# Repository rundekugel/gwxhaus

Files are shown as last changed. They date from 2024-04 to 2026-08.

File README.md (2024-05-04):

# gwxhaus
## Greenhouse Controller

*It's just started, not finished.*

Open hardware and firmware to control a greenhouse heating and cooling. Depends on temperature, humidity, wind and time.

An ESP32 controls the motor-controller and reads sensor data.

### Sensors
- Temperature in/out
- Humidity in/out
- Wind
- Soil moisture

There can be a lot of settings depending on sensor values and time.

### Actors
- Motors to open/close the windows
- Valves to control water
- Relais to control heating

The ESP32 is connected via another ESP32, ESP8266 or RaspberryPi to the WWW. Via mqtt the sensor data and actor positions are stored in a database and can be viewd in charts.

Optional, password protected, it's possible to change the settings and manually control the actors.

If any sensor values are out of range, or power fails, there can be messages sent via email, telegram, SMS, telephone (voip), or other channels.

Weather forecast data from Deutscher Wetterdienst https://dwd.api.bund.dev/ can be used to protect windows against storm or hail.

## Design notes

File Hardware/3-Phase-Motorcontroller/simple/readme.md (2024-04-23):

# gwx-control-motor
## Simple motor controller

Created to control a 3 phase motor to open/close windows of a greenhouse
Created with Eagle Version 7.7

Features:
- switch off motor, if window arrived at end position 
- stop for about 3 seconds, if direction changes, to prevent too high current, which could destroy power switches.

Input: 
- motor on/off
- up/down
- switches for end positions

Output:
- +/- for optocoupler of power motor switcher. Can control DC and AC, 1 to 3 phase motors.
- +/- for direction switch relais

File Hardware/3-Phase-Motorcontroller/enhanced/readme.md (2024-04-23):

# gwx-control-motor-oc
## Enhanced motor controller

Created to control a 3 phase motor to open/close windows of a greenhouse. 
Created with Eagle Version 7.7

Features:
- switch off motor, if direction changes
- switch off motor, if window arrived at end position 

Input: 
- motor on/off
- up/down
- switches for end positions. Optocoupler protected. 

Output:
- +/- for optocoupler of motorswitcher. Can control DC and AC, 1 to 3 phase motors.
- +/- for direction switch relais.

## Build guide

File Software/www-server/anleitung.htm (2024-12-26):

# Steuerung via webseite

Webadresse: https://unteroed.qc9.de/gwxhaus.php

Diese Webseite kann man mit den Browsern von fast allen Smartphones und Computern aufrufen.
z.B.: Android, IPhone, Apple MAC OSX, Windows, Linux.

Auf der Seite können die wichtigsten Informationen abgelesen werden.
Um etwas zu ändern muss man sich anmelden (Login).

Der Login-Knopf ist auf der Webseite unter der letzten Tabelle.

Man kommt dann auf diese Seite: https://unteroed.qc9.de/login.php

Daten eingeben, Knopf drücken, und man landet wieder auf der Startseite. Jetzt gibt es keinen Login-Knopf mehr, dafür ein paar andere.

[Auf] zum Fenster öffnen
[Zu] zum Fenster schliessen
[Stop] um den Motor zu stoppen, wenn man das Fenster halb offen lassen will.

Wenn es wärmer oder kälter oder zu feucht ist, dass wird due Regelung das Fenster sofort wieder in die benötigte Stellung zurückstellen. Das kann man blockieren.

[Manuell] mit diesem Knopf wird die Automatik abgeschaltet. Falls man vergisst, den manuellen Modus abzuschalten, wird der manuelle Modus nach einer bestimmten Zeit wieder abgeschaltet, damit die Planzen nicht kaputt gehen.

Wie lange der manuelle Modus aktiv ist, wird oben in roter Schrift angezeigt.

Ist die Automatik deaktiviert, also der manuelle Modus aktiv, dann gilt das für jeden, der eingeloggt ist.

Jeder Befehl dauert 10 bis 20 sek. bis er ausgeführt wird. Drückt man schnell hintereinander [manuell], haus1[auf] , haus2[auf] so kann es 20 bis 40 sek, dauern bis haus1 aufgeht. und 20 bis 60sek. bis haus2 aufgeht.

Zuviele Befehle nacheinander funktionieren nicht. Dann einfach mal wieder ein bisschen warten.

# Technische Ansicht

In der technischen Ansicht gibt es ein paar Infos mehr und auch mehr Buttons. z.B. kann man in der techn. Ansicht den manuellen Modus auf eine längere Zeit einstellen. Auch im der einfachen Ansicht ist dann der manuelle Modus so lange aktiv. Den Knopf [Set time] bitte nur benutzen, wenn die Zeit mehr als ca. 3min. falsch geht.

Passau, 2024-12-24

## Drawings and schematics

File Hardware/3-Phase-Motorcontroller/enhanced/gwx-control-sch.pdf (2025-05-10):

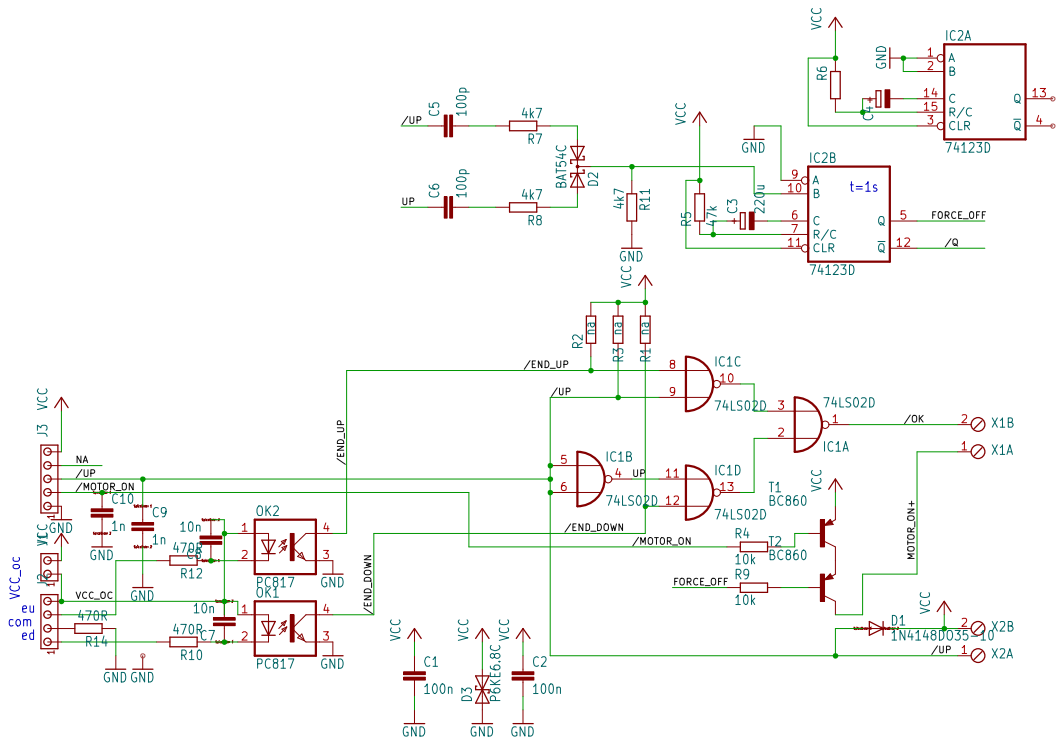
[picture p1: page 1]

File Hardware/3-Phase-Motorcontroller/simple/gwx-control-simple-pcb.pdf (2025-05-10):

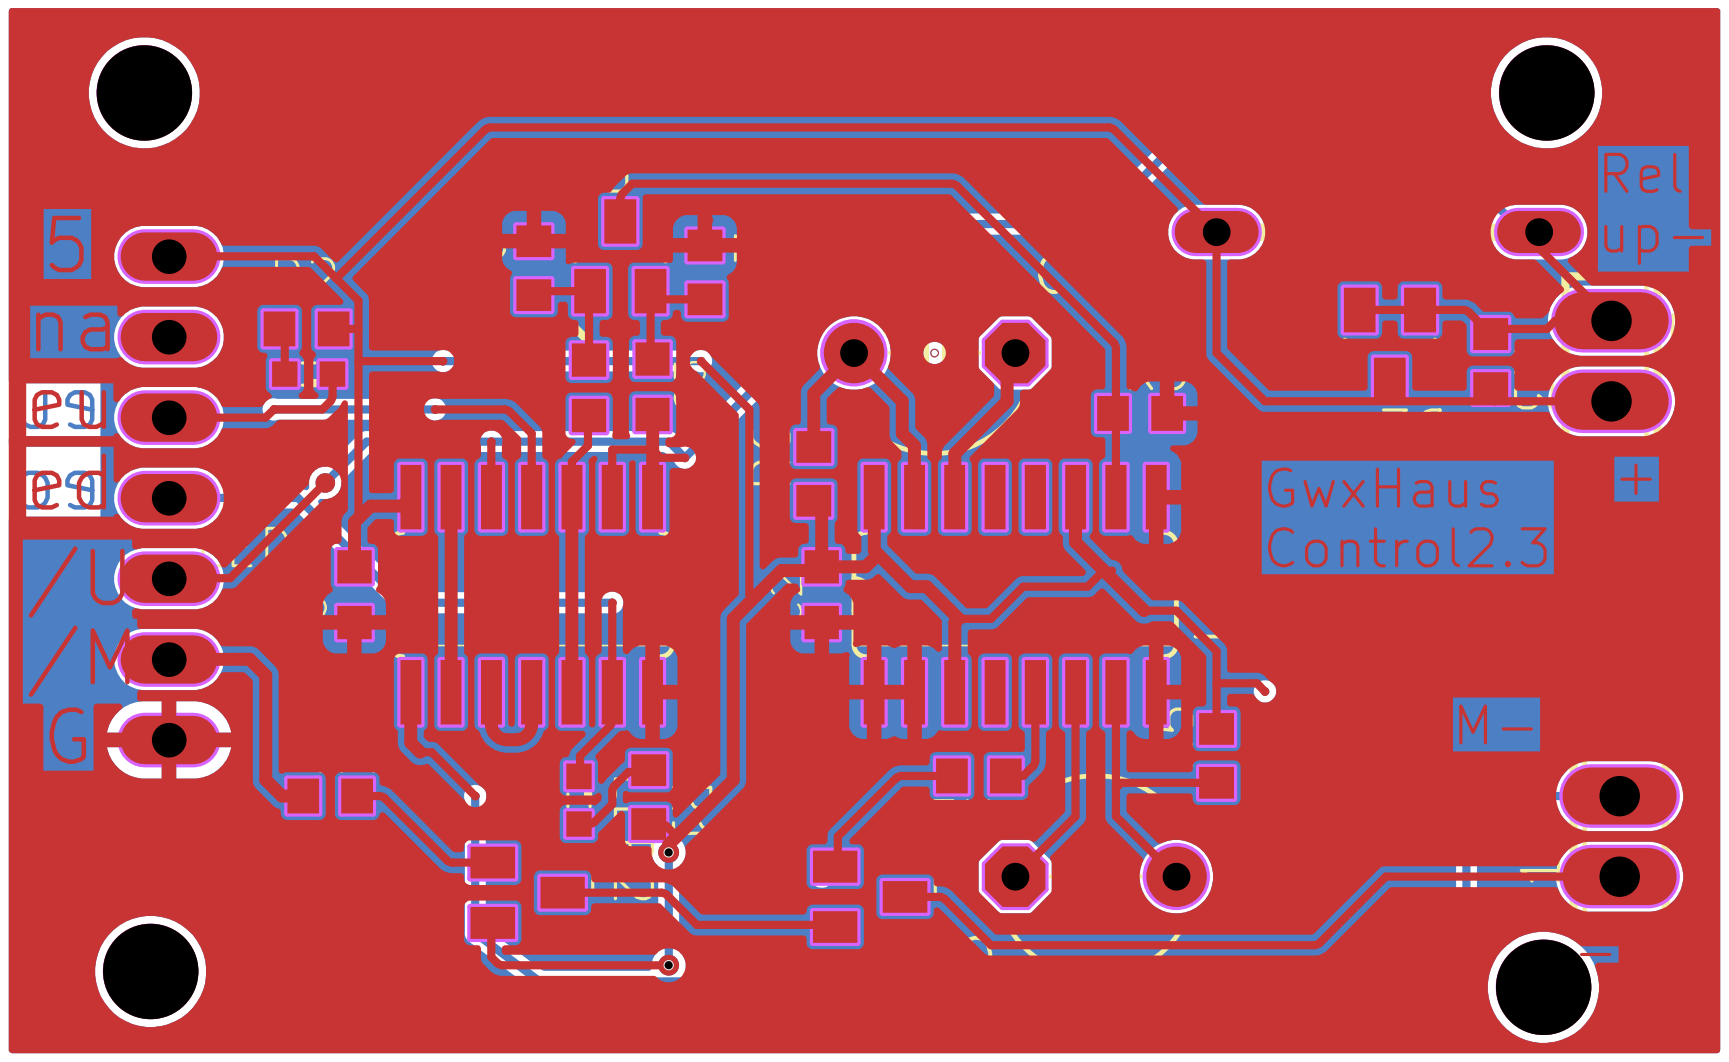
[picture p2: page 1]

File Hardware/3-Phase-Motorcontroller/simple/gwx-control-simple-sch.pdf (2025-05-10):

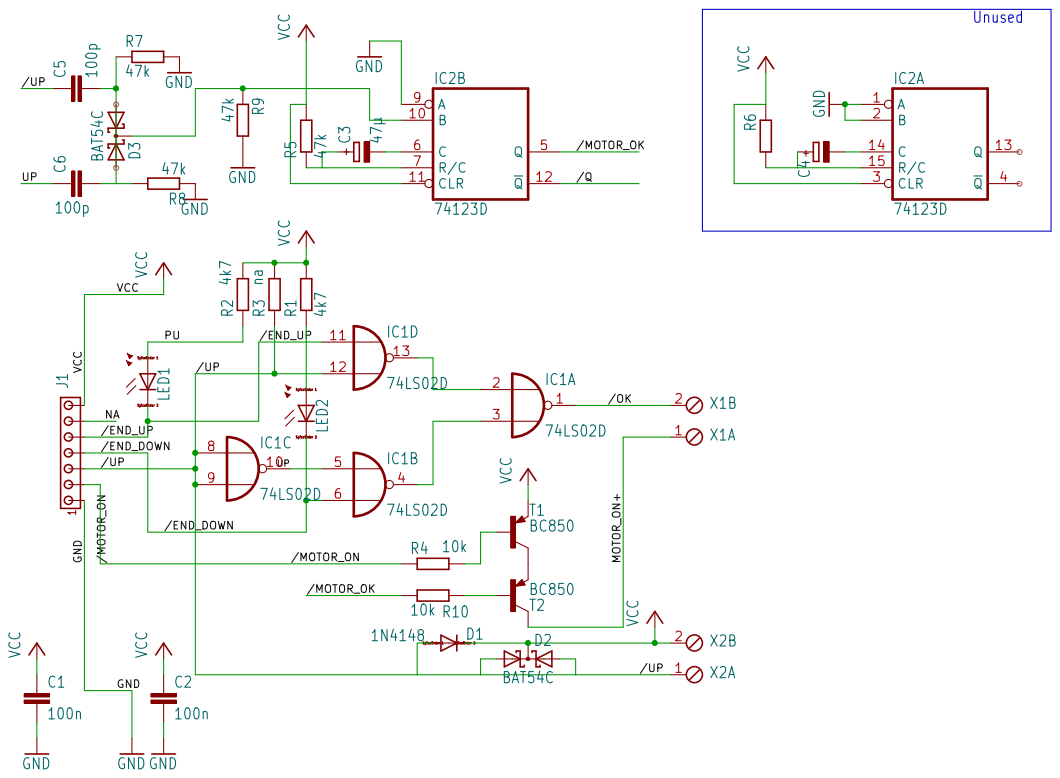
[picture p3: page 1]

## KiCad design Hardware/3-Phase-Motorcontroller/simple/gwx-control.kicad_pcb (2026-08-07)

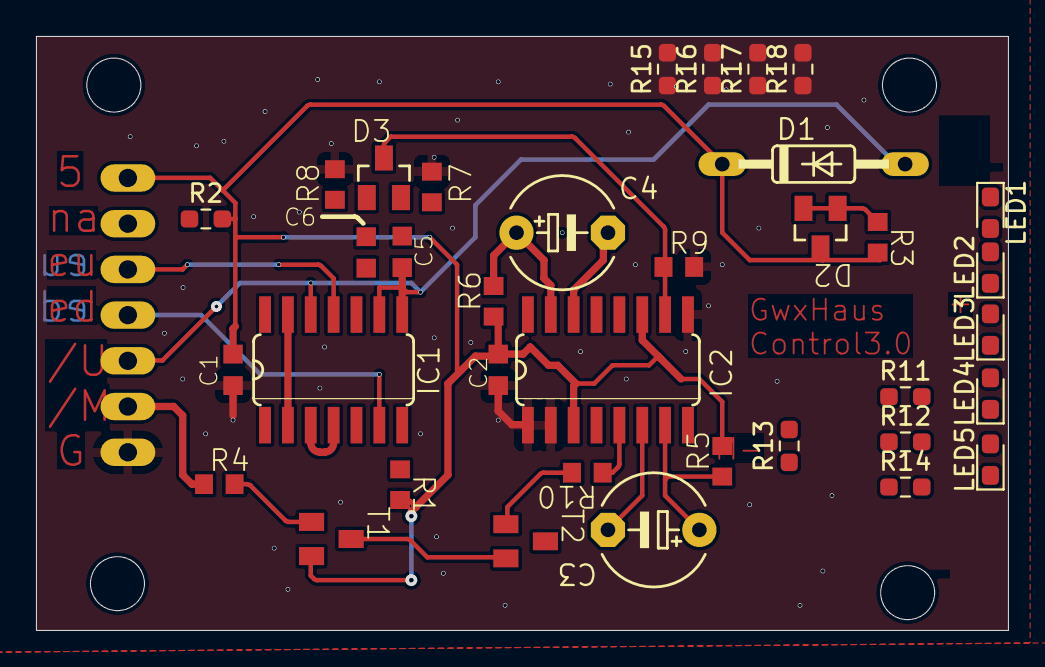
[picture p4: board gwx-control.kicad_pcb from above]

Board: 2 copper layers, 54.0 x 33.0 mm, 41 parts (1 on the bottom side), 22 nets.

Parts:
C1, C2: 100n; C0603K
C3: 47µ; E5-6
C4: CPOL-EUE5-6; E5-6
C5, C6: 1n; C0603K
D1: 1N4148; DO35-10
D2, D3: BAT54C; SOT23
IC1: 74LS02D; SO14
IC2: 74123D; SO16
J1: MTA07-100; 10X07MTA
LED1, LED2, LED3, LED4, LED5: LED_ESML0603; LED_0603_1608Metric_Pad1.05x0.95mm_HandSolder
R1, R3: 4k7; R0603
R2, R11, R12, R13, R14, R17, R18: 4k7; R_0603_1608Metric_Pad0.98x0.95mm_HandSolder
R4, R7, R8, R10: 10k; R0603
R5, R9: 47k; R0603
R6: R-EU_R0603; R0603
R15, R16: 100R; R_0603_1608Metric_Pad0.98x0.95mm_HandSolder
T1, T2: BC850; SOT23-BEC
UNK_HOLE_0: dummyfp0
UNK_HOLE_1: dummyfp1
UNK_HOLE_2: dummyfp2
UNK_HOLE_3: dummyfp3

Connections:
/UP: C6.1, R13.1
//END_DOWN: IC1.6 (I1), R16.1
//END_UP: IC1.11 (I0), R15.1, R17.1
//MOTOR_OK: IC2.5 (Q), R10.1
//MOTOR_ON: J1.2, R4.1
//UP: C5.1, D1.A, D2.1 (A1), D2.2 (A2), IC1.8 (I0), IC1.9 (I1), IC1.12 (I1), J1.3, R3.1, R18.1
GND: C1.2, C2.2, IC2.1 (A), IC2.2 (B), IC2.9 (A), J1.1, R7.2, R8.1, R9.2
unnamed: C5.2, C6.2, R7.1, R8.2
unnamed: D3.3 (CC), IC2.10 (B), R9.1
unnamed: IC1.2 (I0), IC1.13 (O)
unnamed: IC1.3 (I1), IC1.4 (O)
unnamed: IC1.5 (I0), IC1.10 (O)
unnamed: C4.-, IC2.14 (C)
unnamed: C4.+, IC2.15 (R/C), R6.2
unnamed: C3.-, IC2.6 (C)
unnamed: C3.+, IC2.7 (R/C), R5.1
unnamed: J1.4, R16.2
unnamed: J1.5, R15.2
unnamed: R4.2, T1.B
unnamed: R10.2, T2.B
unnamed: T1.C, T2.E
VCC: C1.1, C2.1, D1.C, D2.3 (CC), IC2.3 (CLR), IC2.11 (CLR), J1.7, R1.2, R2.2, R3.2, R5.2, R6.1, R11.2, R12.2, R13.2, R14.2, R17.2, R18.2, T1.E

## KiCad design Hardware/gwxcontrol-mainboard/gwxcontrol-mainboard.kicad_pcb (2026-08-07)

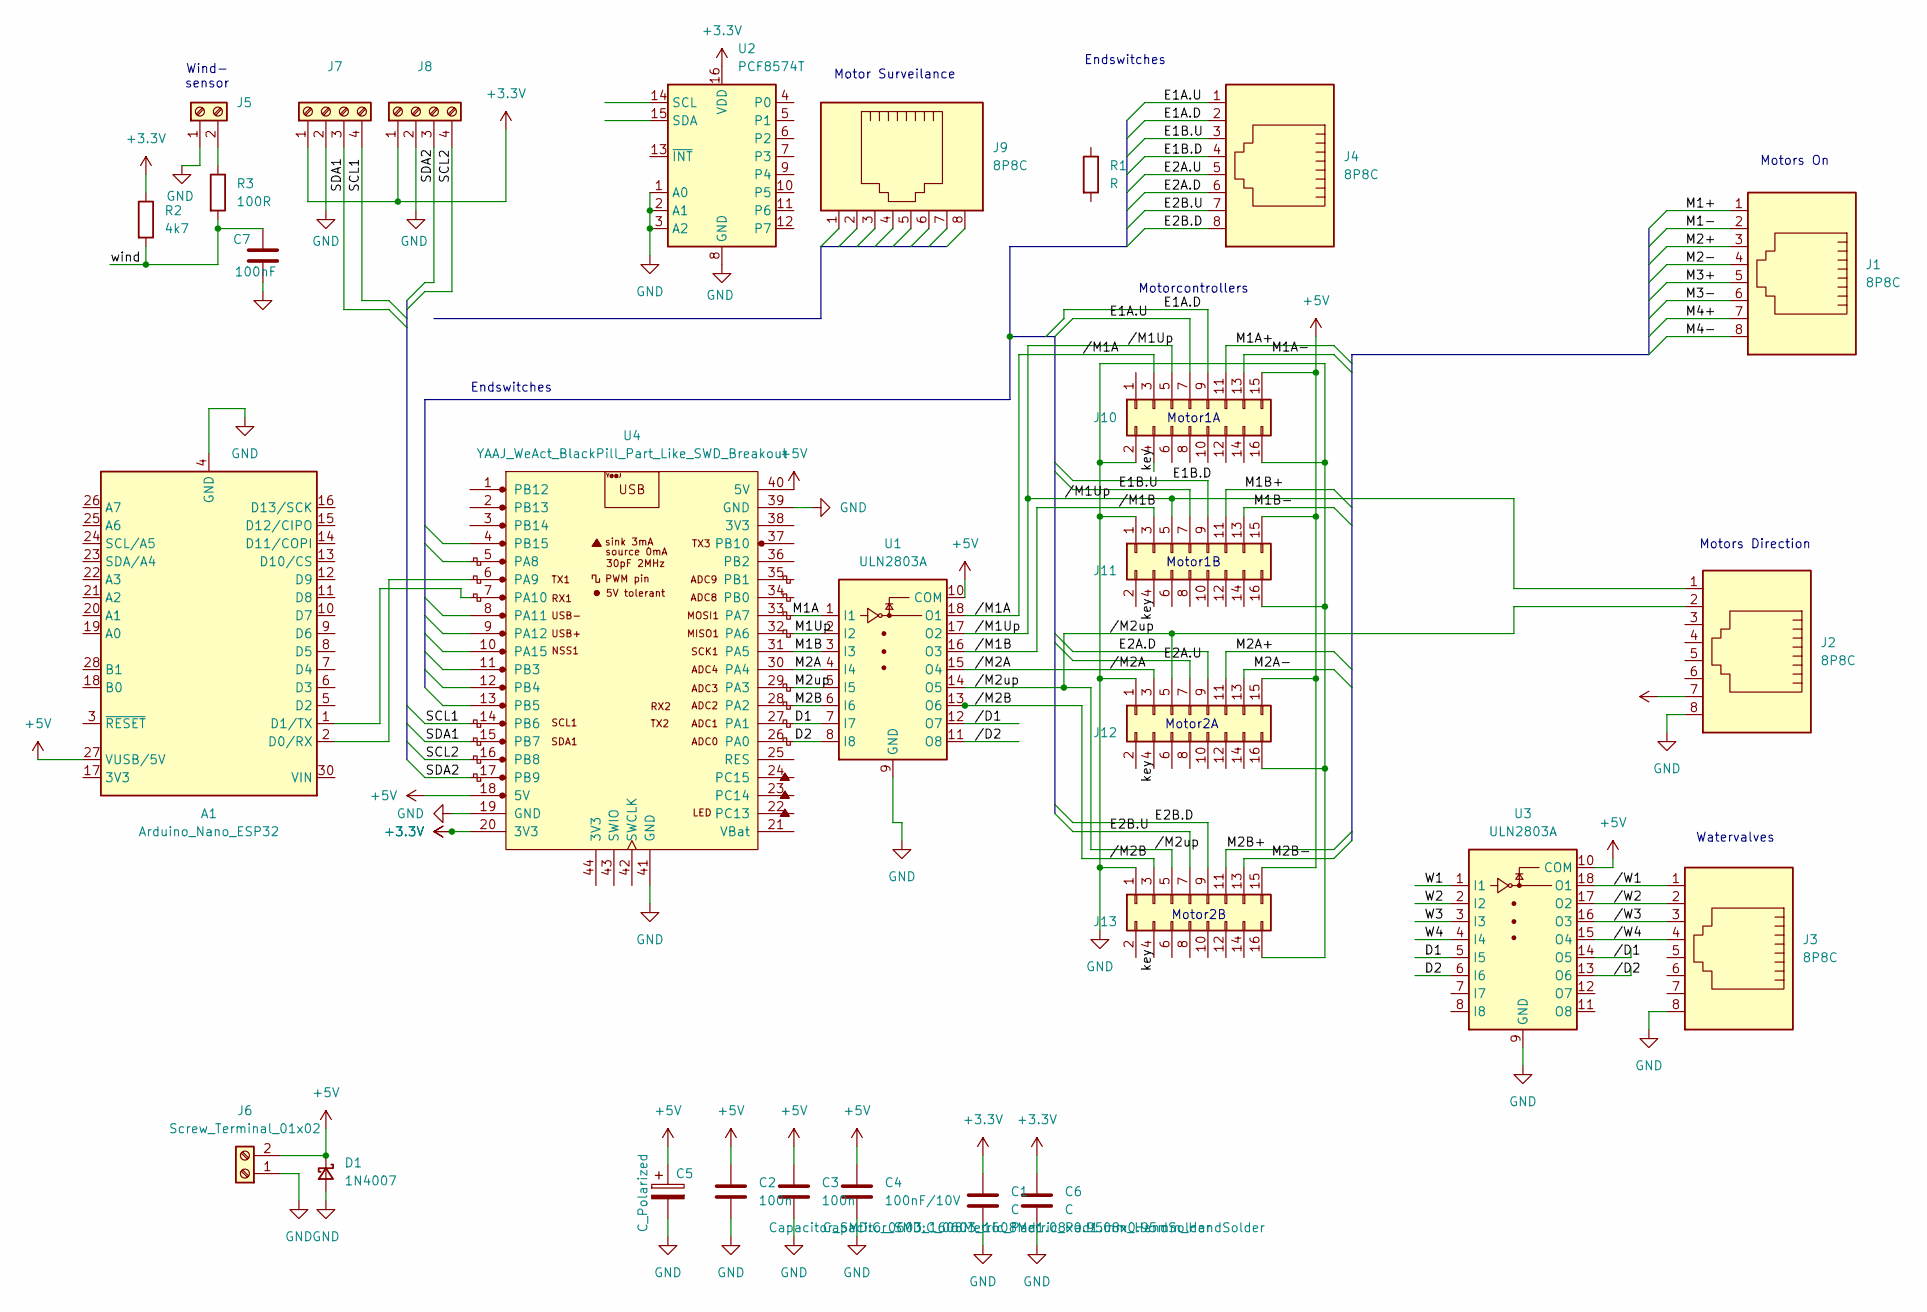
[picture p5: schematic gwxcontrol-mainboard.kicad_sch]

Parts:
A1: Arduino_Nano_ESP32; Arduino_Nano
C1, C6: C; C_0603_1608Metric_Pad1.08x0.95mm_HandSolder
C2, C3: 100n; C_0603_1608Metric_Pad1.08x0.95mm_HandSolder
C4: 100nF/10V; C_0603_1608Metric_Pad1.08x0.95mm_HandSolder
C5: C_Polarized; CP_Radial_D12.5mm_P5.00mm
C7: 100nF; C_0603_1608Metric_Pad1.08x0.95mm_HandSolder
D1: 1N4007; D_DO-41_SOD81_P10.16mm_Horizontal
J1, J2, J3, J4, J9: 8P8C; RJ45_Plug_Metz_AJP92A8813
J5, J6: Screw_Terminal_01x02; TerminalBlock_Phoenix_PTSM-0,5-2-2.5-H-THR_1x02_P2.50mm_Hor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
J7, J8: Screw_Terminal_01x04; TerminalBlock_Phoenix_PTSM-0,5-4-2.5-H-THR_1x04_P2.50mm_Hor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
J10, J11, J12, J13: Conn_02x08_Odd_Even; PinSocket_2x08_P2.54mm_Vertical
R1: R; R_0603_1608Metric_Pad0.98x0.95mm_HandSolder
R2: 4k7; R_0603_1608Metric_Pad0.98x0.95mm_HandSolder
R3: 100R; R_0603_1608Metric_Pad0.98x0.95mm_HandSolder
U1, U3: ULN2803A; DIP-18_W7.62mm_LongPads
U2: PCF8574T; SOIC-16W_7.5x10.3mm_P1.27mm
U4: YAAJ_WeAct_BlackPill_Part_Like_SWD_Breakout; YAAJ_WeAct_BlackPill_2

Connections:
+3.3V: C1.1, C6.1, J7.1, J8.1, R2.1, U2.16 (VDD), U4.20 (3V3)
+5V: A1.27 (VUSB/5V), C2.1, C3.1, C4.1, C5.1, D1.1 (K), J2.7, J6.2, J10.15, J11.15, J12.15, J13.15, U1.10 (COM), U3.10 (COM), U4.18 (5V), U4.40 (5V)
/D1: U1.7 (I7), U3.5 (I5), U4.27 (PA1)
/D2: U1.8 (I8), U3.6 (I6), U4.26 (PA0)
/E1A.D: J4.2, J10.9
/E1A.U: J4.1, J10.7
/E1B.D: J4.4, J11.9
/E1B.U: J4.3, J11.7
/E2A.D: J4.6, J12.9
/E2A.U: J4.5, J12.7
/E2B.D: J4.8, J13.9
/E2B.U: J4.7, J13.7
/M1+: J1.1
/M1-: J1.2
/M1A+: J10.11
/M1A-: J10.13
/M1B: U1.3 (I3), U4.31 (PA5)
/M1B+: J11.11
/M1B-: J11.13
/M1Up: U1.2 (I2), U4.32 (PA6)
/M2+: J1.3
/M2-: J1.4
/M2A: U1.4 (I4), U4.30 (PA4)
/M2A+: J12.11
/M2A-: J12.13
/M2B: U1.6 (I6), U4.28 (PA2)
/M2B+: J13.11
/M2B-: J13.13
/M2up: U1.5 (I5), U4.29 (PA3)
/M3+: J1.5
/M3-: J1.6
/M4+: J1.7
/M4-: J1.8
/SCL1: J7.4, U4.14 (PB6)
/SCL2: J8.4, U4.16 (PB8)
/SDA1: J7.3, U4.15 (PB7)
/SDA2: J8.3, U4.17 (PB9)
/W1: U3.1 (I1)
/W2: U3.2 (I2)
/W3: U3.3 (I3)
/W4: U3.4 (I4)
/key: J10.4
/wind: C7.2, R2.2, R3.2
//D1: U1.12 (O7), U3.14 (O5)
//D2: U1.11 (O8), U3.13 (O6)
//M1A: J10.3, U1.18 (O1)
//M1B: J11.3, U1.16 (O3)
//M1Up: J2.1, J10.5, J11.5, U1.17 (O2)
//M2A: J12.3, U1.15 (O4)
//M2B: J13.3, U1.13 (O6)
//M2up: J2.2, J12.5, J13.5, U1.14 (O5)
//W1: J3.1, U3.18 (O1)
//W2: J3.2, U3.17 (O2)
//W3: J3.3, U3.16 (O3)
//W4: J3.4, U3.15 (O4)
GND: A1.4 (GND), A1.29 (GND), C1.2, C2.2, C3.2, C4.2, C5.2, C6.2, C7.1, D1.2 (A), J2.8, J3.8, J5.1, J6.1, J7.2, J8.2, J10.2, J10.16, J11.1, J11.16, J12.1, J12.16, J13.1, J13.16, U1.9 (GND), U2.1 (A0), U2.2 (A1), U2.3 (A2), U2.8 (GND), U3.9 (GND), U4.19 (GND), U4.39 (GND), U4.41 (GND)
unnamed: A1.2 (D0/RX), U4.6 (PA9)
unnamed: A1.1 (D1/TX), U4.7 (PA10)
unnamed: J5.2, R3.1
unnamed: U1.1 (I1), U4.33 (PA7)

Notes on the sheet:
Endswitches
Watervalves
Wind- sensor
Motors Direction
Motor1A
Motor Surveilance
Motor2B
Motorcontrollers
Motor1B
Motors On
Motor2A

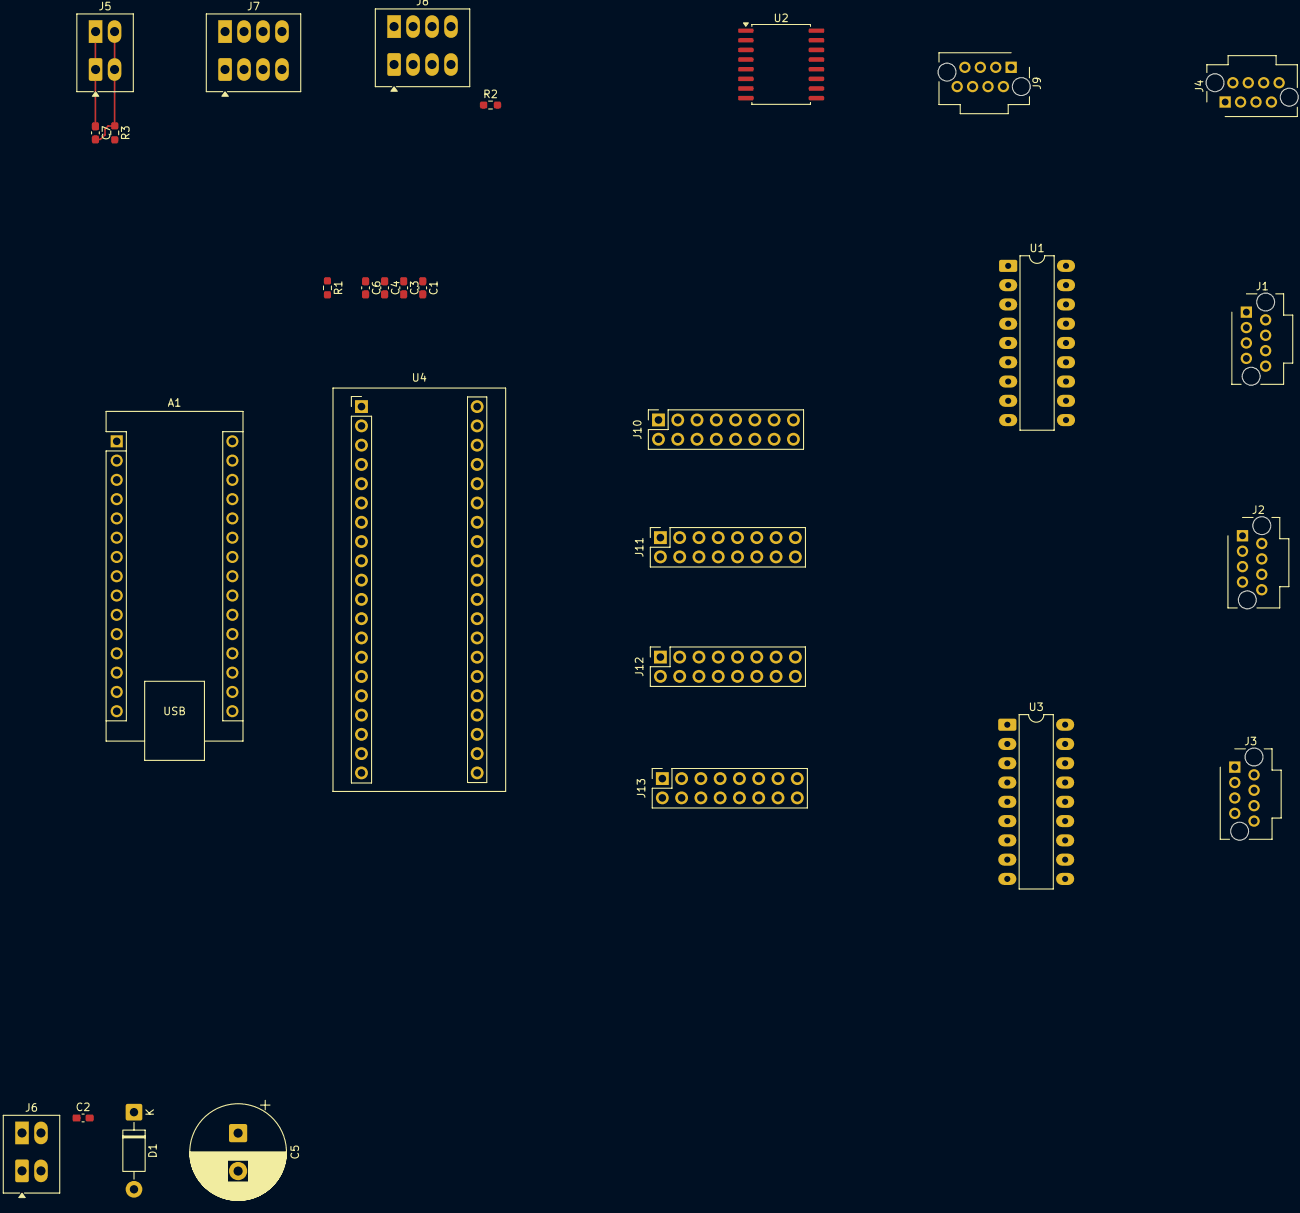
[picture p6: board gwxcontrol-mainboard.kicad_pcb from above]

Board: 2 copper layers, 29 parts (0 on the bottom side), 39 nets.

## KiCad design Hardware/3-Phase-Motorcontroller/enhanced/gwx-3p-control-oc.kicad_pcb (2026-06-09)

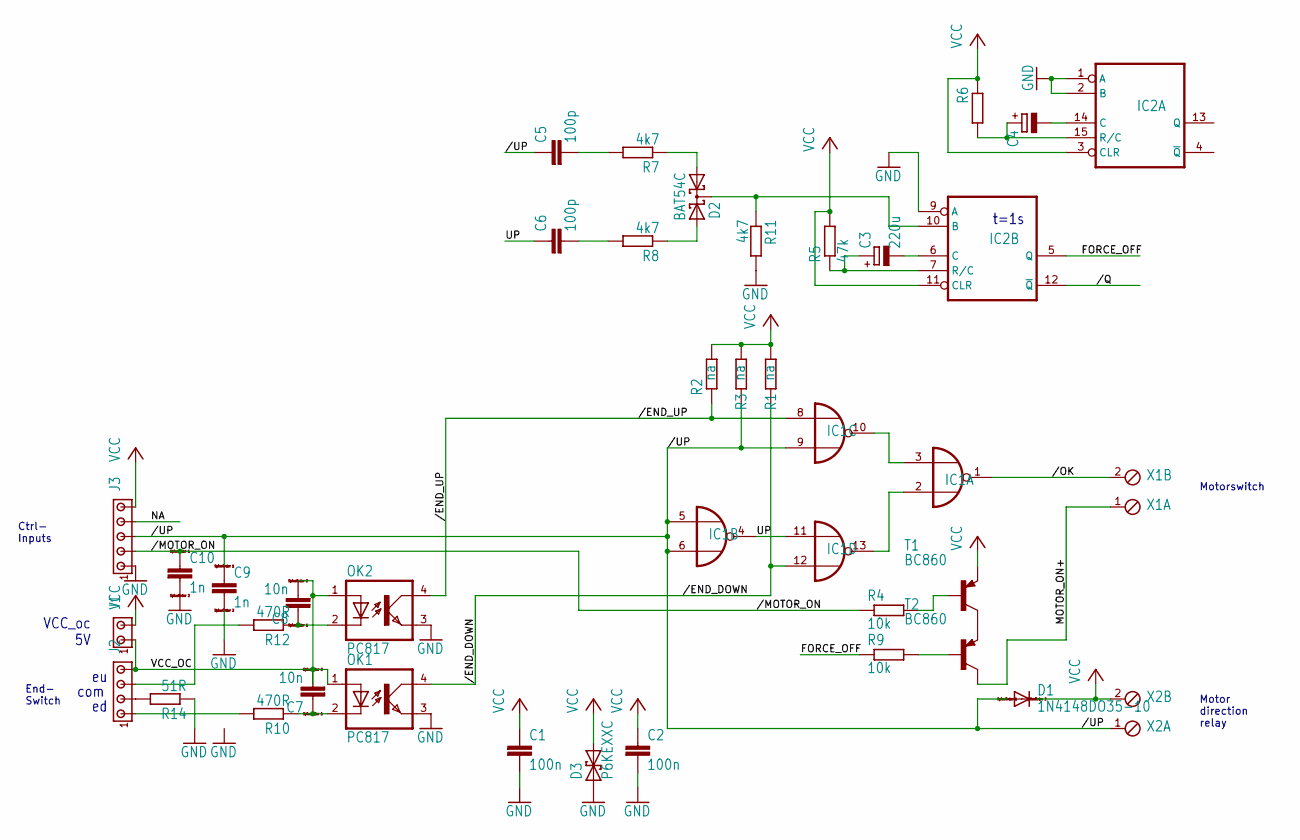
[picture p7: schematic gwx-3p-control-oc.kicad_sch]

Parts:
C1, C2: 100n; C0603K
C3: 220u; E5-6
C4: CPOL-EUE5-6; E5-6
C5, C6: 100p; C0603K
C7, C8: 10n; C0603
C9, C10: 1n; C0603
D1: 1N4148DO35-10; DO35-10
D2: BAT54C; SOT23
D3: P6KEXXC; CB417-15
IC1: 7402D; SO14
IC2: 74123D; SO16
J1: MTA02-100; 10X02MTA
J2: MTA04-100; 10X04MTA
J3: MTA05-100; 10X05MTA
OK1, OK2: PC817; DIL04
R1, R2, R3: na; R0603
R4, R9: 10k; R0603
R5: 47k; R0603
R6: R-EU_R0603; R0603
R7, R8, R11: 4k7; R0603
R10, R12: 470R; R0603
R14: 51R; R_0603_1608Metric
T1, T2: BC860; SOT23-BEC
X1, X2: MPT2; 2POL254

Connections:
/ED: J2.1, R10.2
/END_DOWN: IC1.12 (I1), OK1.4 (COL), R1.1
/END_UP: IC1.8 (I0), OK2.4 (COL), R2.1
/EU: J2.3, R12.2
/MOTOR_ON: C10.1, J3.2, R4.1
/OK: IC1.1 (O), X1.2
/Q: IC2.12 (~Q)
/UP: C5.1, C9.1, D1.A, IC1.5 (I0), IC1.6 (I1), IC1.9 (I1), J3.3, R3.1, X2.1
ECOM: J2.2, R14.2
FORCE_OFF: IC2.5 (Q), R9.1
GND: C1.2, C2.2, C9.2, C10.2, D3.A (1), IC1.7 (GND), IC2.1 (A), IC2.2 (B), IC2.8 (GND), IC2.9 (A), J3.1, OK1.3 (EMIT), OK2.3 (EMIT), R11.2, R14.1; also elsewhere on the board
MOTOR_ON+: T2.C, X1.1
unnamed: C3.+, IC2.7 (R/C), R5.1
unnamed: C3.-, IC2.6 (C)
unnamed: C4.+, IC2.15 (R/C), R6.2
unnamed: C5.2, R7.2
unnamed: IC1.3 (I1), IC1.10 (O)
unnamed: IC1.2 (I0), IC1.13 (O)
unnamed: C6.2, R8.2
unnamed: D2.3 (CC), IC2.10 (B), R11.1
unnamed: C4.-, IC2.14 (C)
unnamed: R4.2, T1.B
unnamed: R9.2, T2.B
unnamed: T1.C, T2.E
unnamed: D2.1 (A1), R7.1
unnamed: C7.1, OK1.2 (C), R10.1
unnamed: C8.1, OK2.2 (C), R12.1
unnamed: D2.2 (A2), R8.1
UP: C6.1, IC1.4 (O), IC1.11 (I0)
VCC: C1.1, C2.1, D1.C, D3.C (2), IC1.14 (VCC), IC2.3 (CLR), IC2.11 (CLR), IC2.16 (VCC), J1.2, J3.5, R1.2, R2.2, R3.2, R5.2, R6.1, T1.E, X2.2
VCC_OC: C7.2, C8.2, J1.1, J2.4, OK1.1 (A), OK2.1 (A)

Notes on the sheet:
VCC_oc 5V
Motorswitch
com
Motor direction relay
End- Switch
t=1s
Ctrl- Inputs

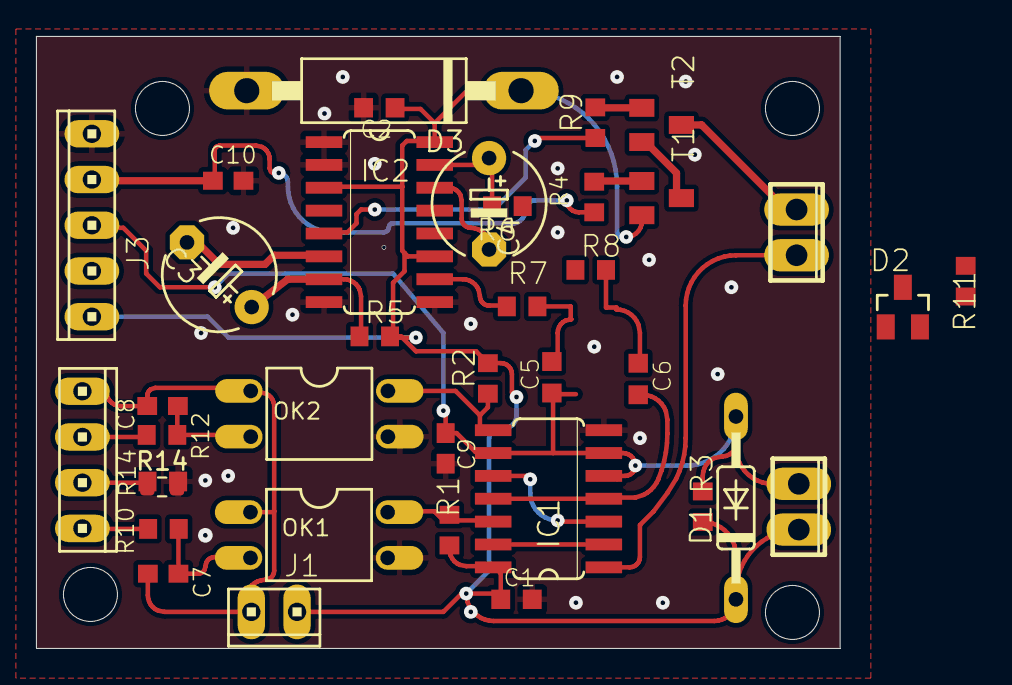
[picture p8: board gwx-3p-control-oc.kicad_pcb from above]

Board: 2 copper layers, 44.6 x 34.0 mm, 42 parts (0 on the bottom side), 30 nets.

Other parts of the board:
@HOLE0, @HOLE1, @HOLE2, @HOLE3: (no value)
R14#2: 51R; R_0603_1608Metric

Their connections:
GND: R14#2.1; also elsewhere on the board

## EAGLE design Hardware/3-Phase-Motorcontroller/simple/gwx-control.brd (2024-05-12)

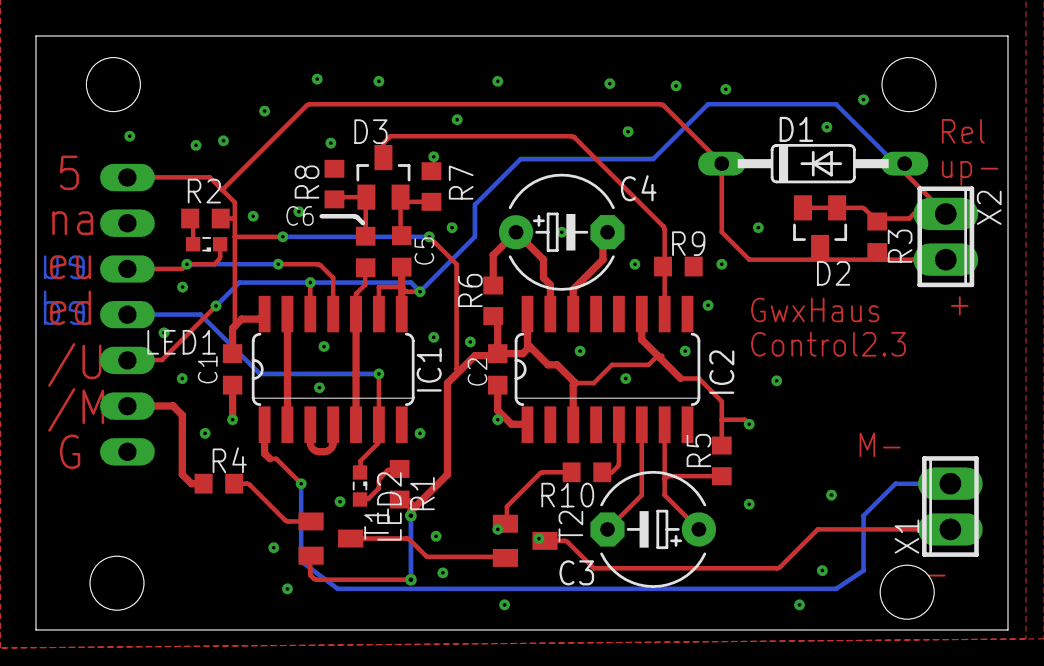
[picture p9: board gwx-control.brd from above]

Board: 2 copper layers, 54.0 x 33.0 mm, 28 parts (1 on the bottom side), 24 nets.

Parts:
C1, C2: 100n; C0603K
C3: 47µ; E5-6
C4: E5-6
C5, C6: 100p; C0603K
D1: 1N4148; DO35-10
D2, D3: BAT54C; SOT23
IC1: 74LS02D; SO14
IC2: 74LS123D; SO16
J1: 10X07MTA
LED1, LED2: LED_SML0603
R1, R2: 4k7; R0603
R3: na; R0603
R4, R10: 10k; R0603
R5, R7, R8, R9: 47k; R0603
R6: R0603
T1, T2: BC850; SOT23-BEC
X1, X2: 2POL254

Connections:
/END_DOWN: IC1.6, J1.4, LED2.C
/END_UP: IC1.11, J1.5, LED1.C
/MOTOR_OK: IC2.5, R10.1
/MOTOR_ON: J1.2, R4.1
/OK: IC1.1, X1.2
/UP: C5.1, D1.A, D2.1, D2.2, IC1.8, IC1.9, IC1.12, J1.3, R3.1, X2.1
GND: C1.2, C2.2, IC1.7, IC2.1, IC2.2, IC2.8, IC2.9, J1.1, R7.2, R8.1, R9.2
MOTOR_ON+: T2.C, X1.1
unnamed: C3.+, IC2.7, R5.1
unnamed: C3.-, IC2.6
unnamed: C4.+, IC2.15, R6.2
unnamed: C5.2, D3.2, R7.1
unnamed: IC1.2, IC1.13
unnamed: IC1.3, IC1.4
unnamed: C6.2, D3.1, R8.2
unnamed: D3.3, IC2.10, R9.1
unnamed: C4.-, IC2.14
unnamed: R10.2, T2.B
unnamed: R4.2, T1.B
unnamed: T1.C, T2.E
unnamed: LED2.A, R1.1
PU: LED1.A, R2.1
UP: C6.1, IC1.5, IC1.10
VCC: C1.1, C2.1, D1.C, D2.3, IC1.14, IC2.3, IC2.11, IC2.16, J1.7, R1.2, R2.2, R3.2, R5.2, R6.1, T1.E, X2.2

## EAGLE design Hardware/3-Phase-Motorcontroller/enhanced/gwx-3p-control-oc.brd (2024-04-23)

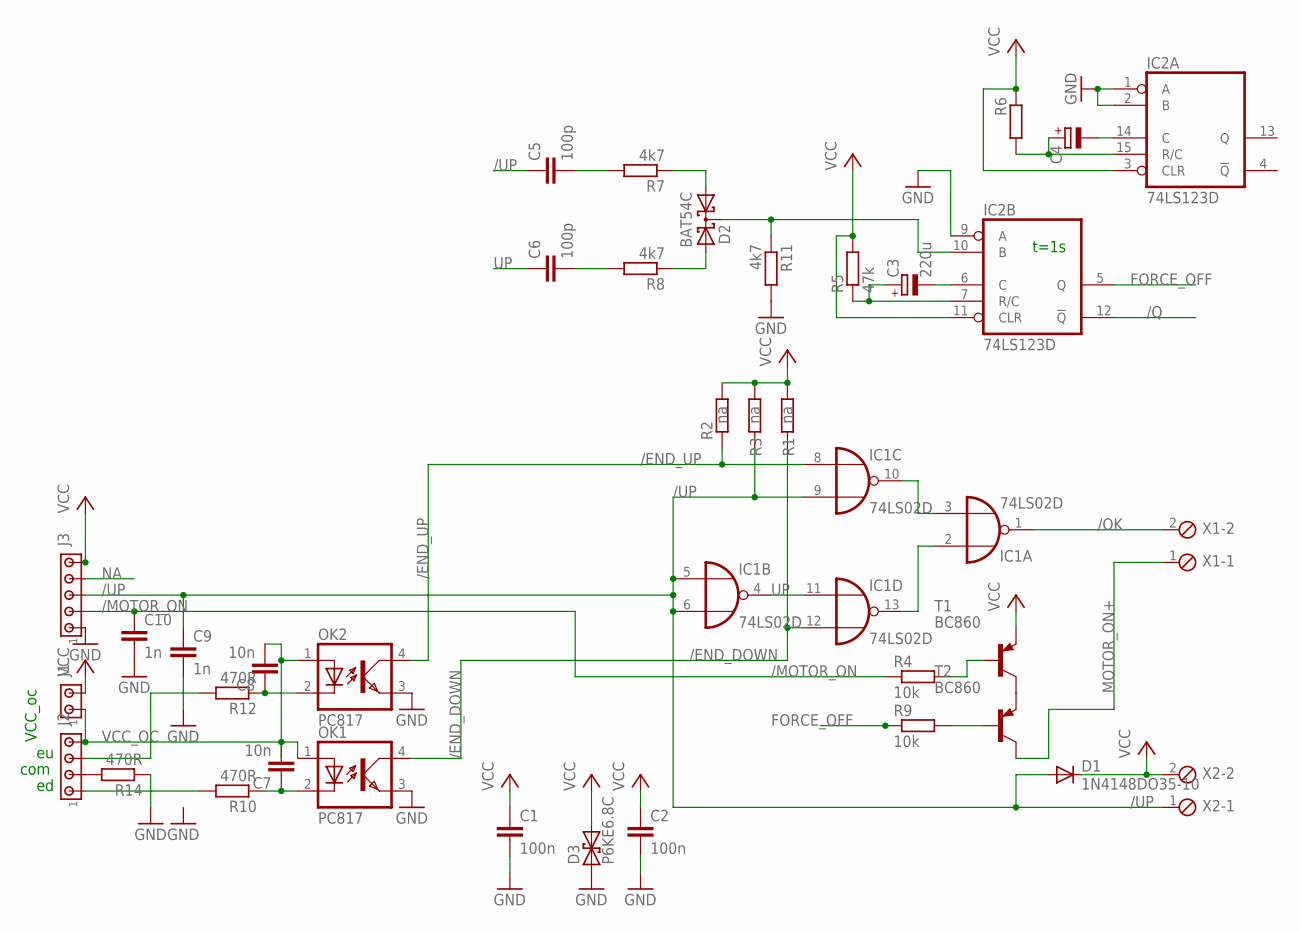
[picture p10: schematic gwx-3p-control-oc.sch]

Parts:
C1, C2: 100n; C0603K
C3: 220u; E5-6
C4: CPOL-EUE5-6; E5-6
C5, C6: 100p; C0603K
C7, C8: 10n; C0603
C9, C10: 1n; C0603
D1: 1N4148DO35-10; DO35-10
D2: BAT54C; SOT23
D3: P6KE6.8C; CB417-15
IC1: 74LS02D; SO14
IC2: 74LS123D; SO16
J1: MTA02-100; 10X02MTA
J2: MTA04-100; 10X04MTA
J3: MTA05-100; 10X05MTA
OK1, OK2: PC817; DIL04
R1, R2, R3: na; R0603
R4, R9: 10k; R0603
R5: 47k; R0603
R6: R-EU_R0603; R0603
R7, R8, R11: 4k7; R0603
R10, R12, R14: 470R; R0603
T1, T2: BC860; SOT23-BEC
X1, X2: MPT2; 2POL254

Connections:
/ED: J2.1, R10.2
/END_DOWN: IC1.12 (I1), OK1.4 (COL), R1.1
/END_UP: IC1.8 (I0), OK2.4 (COL), R2.1
/EU: J2.3, R12.2
/MOTOR_ON: C10.1, J3.2, R4.1
/OK: IC1.1 (O), X1.2
/Q: IC2.12 (!Q)
/UP: C5.1, C9.1, D1.A, IC1.5 (I0), IC1.6 (I1), IC1.9 (I1), J3.3, R3.1, X2.1
ECOM: J2.2, R14.2
FORCE_OFF: IC2.5 (Q), R9.1
GND: C1.2, C2.2, C9.2, C10.2, D3.A (1), IC1.7 (GND), IC2.1 (A), IC2.2 (B), IC2.8 (GND), IC2.9 (A), J3.1, OK1.3 (EMIT), OK2.3 (EMIT), R11.2, R14.1
MOTOR_ON+: T2.C, X1.1
unnamed: C3.+, IC2.7 (R/C), R5.1
unnamed: C3.-, IC2.6 (C)
unnamed: C4.+, IC2.15 (R/C), R6.2
unnamed: C5.2, R7.2
unnamed: IC1.3 (I1), IC1.10 (O)
unnamed: IC1.2 (I0), IC1.13 (O)
unnamed: C6.2, R8.2
unnamed: D2.3 (CC), IC2.10 (B), R11.1
unnamed: C4.-, IC2.14 (C)
unnamed: R4.2, T1.B
unnamed: R9.2, T2.B
unnamed: T1.C, T2.E
unnamed: D2.1 (A1), R7.1
unnamed: C7.1, OK1.2 (C), R10.1
unnamed: C8.1, OK2.2 (C), R12.1
unnamed: D2.2 (A2), R8.1
UP: C6.1, IC1.4 (O), IC1.11 (I0)
VCC: C1.1, C2.1, D1.C, D3.C (2), IC1.14 (VCC), IC2.3 (CLR), IC2.11 (CLR), IC2.16 (VCC), J1.2, J3.5, R1.2, R2.2, R3.2, R5.2, R6.1, T1.E, X2.2
VCC_OC: C7.2, C8.2, J1.1, J2.4, OK1.1 (A), OK2.1 (A)

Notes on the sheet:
t=1s
VCC_oc
com

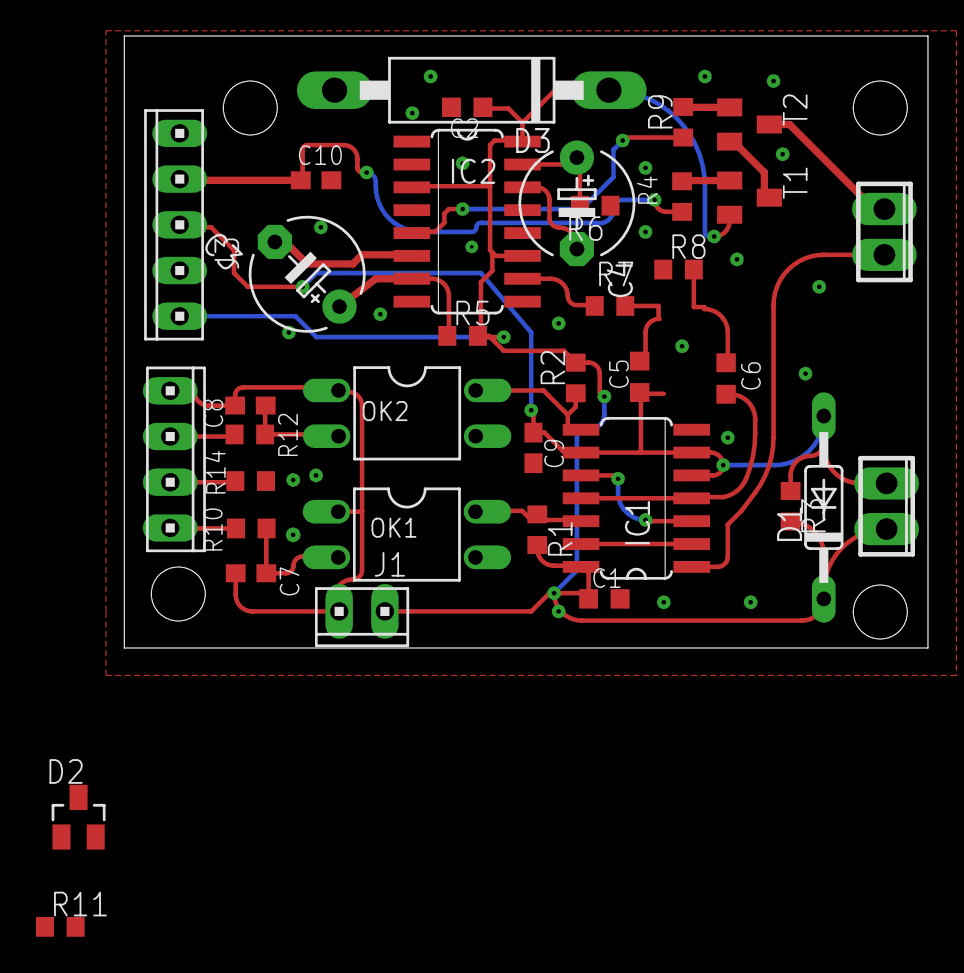
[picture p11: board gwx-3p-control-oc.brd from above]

Board: 2 copper layers, 44.6 x 34.0 mm, 37 parts (0 on the bottom side), 30 nets.

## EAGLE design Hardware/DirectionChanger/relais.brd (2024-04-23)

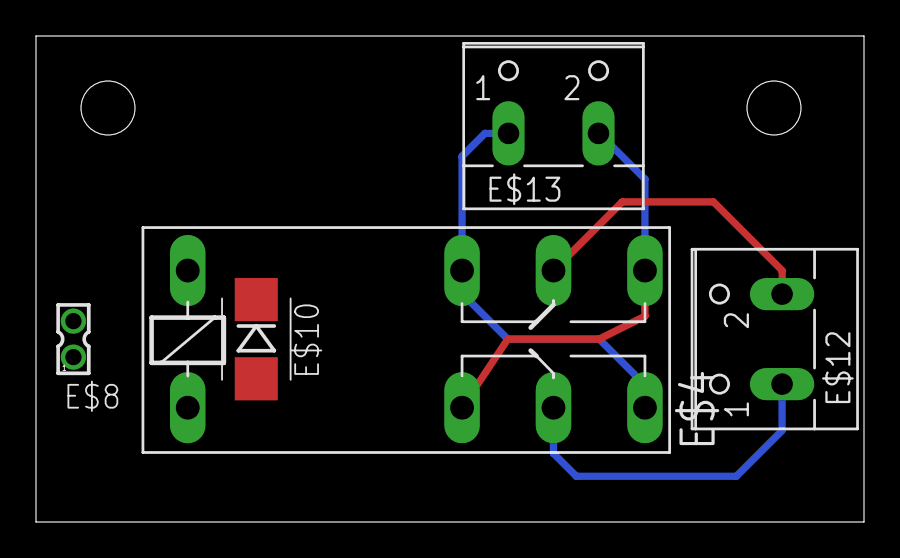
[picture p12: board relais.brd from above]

Board: 2 copper layers, 46.0 x 27.0 mm, 5 parts (0 on the bottom side), 2 nets.

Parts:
E$4: F4052
E$8: 332-02
E$10: SMB
E$12, E$13: W237-102

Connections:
S$5: E$4.O1, E$4.S2
S$9: E$4.O2, E$4.S1

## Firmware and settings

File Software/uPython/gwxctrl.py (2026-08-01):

# gwxcontroller main core
"""
this code is intended to run on a esp32light with 2x13 pins

used pins:
pins 12,14,25,26,27,33 are all output and go to a buffer ic
pins 4,5 are for i2c1
pins 2.15 are for i2c2
pins 16,17 are for UART to wifi-esp32
pins 18,19,23 are for future usage (water-valves / heating / general purpose usage)
pin 13 windsensor
pin 22 on board led, used for heartbeat
pin 39 is used to measure battery voltage
pin 36 is used to measure power supply

unused:
pin 0,34,35

explanation for config parameter 'mot_openpersec1' and 'mot_openpersec2' for haus1/haus2 
 the value is, how far the window opens in one second. value in percent.
 
"""

import time
import json
import os
# this is for a simulator:
if not "ESP" in os.uname().machine:
    import sys
    sys.path.append("upyemu")

import machine, esp32
from machine import Pin, RTC, deepsleep, WDT
# from ucryptolib import aes
# from os import urandom
from binascii import hexlify
# from hashlib import sha256

# local libs:
import windsensor
import HYT221 
import comu
import docrypt

try:
    import revisionfile
except:
    class revisionfile:
        revision = "0000000"
        buildnumber = "0"

__revision__ = revisionfile.revision
__buildnumber__ = revisionfile.buildnumber
__version__ = "0.5.3-" + __revision__ + "-Build:" + str(revisionfile.buildnumber)

# ALLOWED_UART_VARS_W = ("loop_sleep","verbosity")
SECRET_GLOBS = ("ak", "watertables")   # don't display this value to public
DO_NOT_UPDATE = ("test_activated", "illegal")
DURATION_PER_LOOP_MAX = 9
MODE_CBC = 2
MOTOR_END_DELAY = 2  # delay motor switch off, if pos0 reached

USE_END_SWITCHES = 0
DIRECTION_SWITCH_DELAY_MS = 1000 # if direction switches, motorpower must be securely off
POWER_SWITCH_DELAY_MS = 200

# pinning for esp32-lite
PIN_WIND = 13   # Pin(35, Pin.IN, pull=Pin.PULL_UP)    # pin35 is also ADC1_7
PIN_SCL1 = 5
PIN_SDA1 = 4
PIN_SCL2 = 2
PIN_SDA2 = 15
PIN_LED1 = Pin(22, Pin.OUT)  # on bigger boards it's pin2

PIN_WATER1 = Pin(27, Pin.OUT)
PIN_WATER2 = Pin(33, Pin.OUT)
PIN_WATER3 = Pin(32, Pin.OUT)
PIN_WATER4 = Pin(18, Pin.OUT)

PIN_MOTOR1 = Pin(25, Pin.OUT)   # hi=on
PIN_MOTOR1D = Pin(26, Pin.OUT)  # hi=up
PIN_MOTOR2 = Pin(12, Pin.OUT)   # hi=on
PIN_MOTOR2D = Pin(14, Pin.OUT)  # hi=up

PIN_END1UP = Pin(34, Pin.IN)
PIN_END1DOWN = Pin(23, Pin.IN, pull=Pin.PULL_UP)
PIN_END2UP = Pin(35, Pin.IN)    # pin35 can only be input
PIN_END2DOWN = Pin(19, Pin.IN, pull=Pin.PULL_UP)

DOSE1 = Pin(18, Pin.OUT)
DOSE2 = Pin(18, Pin.OUT)
DOSE3 = Pin(18, Pin.OUT)
DOSE4 = Pin(18, Pin.OUT)
DOSEN = [DOSE1, DOSE2, DOSE3, DOSE4]

ADC_BATT = machine.ADC(39)      # VN
PINNUM_POWER = 36   # needed for wakeup
ADC_POWER = machine.ADC(PINNUM_POWER)     # VP
# pins 32+33 are xtal32
# 22,21: scl/sda esp8266?
# esp32: scl/sda: 25/26 ; 18/19


class globs:
    """global variables"""
    verbosity = 2
    cfgfile = "gwxctrl.cfg"
    ws, hy1, hy2 = None, None, None
    serv = None
    inited=False
    rx = []
    port = 80
    dorun = True
    cfg = {"vccok":[4,30e3], "dsonbat":[[3.5,60e3],[3.3,300e3]], 
        "sensf1":50,"sensf2":50, "mot_openpersec1":1.2, "mot_openpersec2":1.3,
        "sturm":10.1, "wind": {"max": 7.1, "openmax":None}
        }
    lasttime = 0
    todos = [("15:00","nop")]
    loop_sleep = 1 # we are slow enough. 1 sec. is enough.
    sturm = 0
    sturmdelay_on = 3
    sturmdelay_off = 30
    deepsleep_ms = 0
    lightsleep_ms = 0
    iv = b""
    modcfg = ""
    wdttime = 90
    manually_timeend = 0
    # checkFensterPosition_lastTime = time.time()
    checkWindowPosition_lastTime = 0
    window_virtual_open = [0,0] # value in percent
    # window_virtual_open2 = 0
    watertables = [180*b"\0"]*4
    test_activated = False  # for debug don't change here, but in config-file!
    window_pos_dest = [None,None]
    windowpos_map = [{"d":0, "u":100, "h":50,"s":None},{"d":0, "u":100, "h":50,"s":None}]
    window_pos_toleranz = 10   # percent
    motor_delay = [0,0]
    alarms = []
    
def servCB(msg=None):
    """this is called for incoming data"""
    if globs.verbosity:
        print("m:"+str(msg))
    globs.rx.append(msg)

def doMotors():
    """
    switch motors,
    depending on globs.window_pos_dest and globs.window_virtual_open.
    
    globs.motor_delay is used to drive the motors to end-position, for the case, if
    virtual motor position is at the end, but not the physical position.
    until now, it's only used to close the windows properly.
    """
    for num in (0,1):
        if globs.window_pos_dest[num] is None: #stop!
            setMotor(num + 1, "0")
            continue
        motordir = getMotor(num+1)
        if globs.window_pos_dest[num] > globs.window_virtual_open[num]:
            # too less open
            if motordir == 'd' and globs.window_pos_dest[num] <100:
                # destination is somewhere in the middle. stop.
                globs.window_pos_dest[num] = None
                setMotor(num + 1, "s")
                continue
            setMotor(num +1, "u")
            globs.motor_delay[num] = MOTOR_END_DELAY
        if globs.window_pos_dest[num] < globs.window_virtual_open[num]:
            # too wide open
            if motordir == 'u' and globs.window_pos_dest[num] >0:
                # destination is somewhere in the middle. stop.
                globs.window_pos_dest[num] = None
                continue
            setMotor(num +1, "d")
            globs.motor_delay[num] = MOTOR_END_DELAY
        if globs.window_pos_dest[num] == globs.window_virtual_open[num]:
            if globs.motor_delay[num]:
                globs.motor_delay[num] -=1
            else:
                globs.window_pos_dest[num] = None


def setMotor(num, direction):
    """
    set the pins to control the motors
    direction: u=up; d=down; s=stop; 0=stop
    """
    if globs.verbosity:
        print("m:", num, direction)
    if not isinstance(num, int):
        num = int(str(num).replace("'", "")[-1])
    d = str(direction).strip().replace("'", "")[-1].lower()
    sw = {"0": [0, 0], "d": [1, 0], "u": [1, 1], "o": [0, 0], "s": [0, 0]}  # pinoutput for: motor,direction
    sw2 = sw.get(d, None)
    if not sw2 or num <1 or num >2:
        print("Warning: wrong values:", num, direction)
        return
    pd = [PIN_MOTOR1D, PIN_MOTOR2D][num-1]
    pm = [PIN_MOTOR1, PIN_MOTOR2][num-1]
    old,new = pd.value(), sw2[1]
    if old != new:   
        # direction changed, wait for motor to stop
        pm.value(0)
        time.sleep_ms(DIRECTION_SWITCH_DELAY_MS)
        pd.value(sw2[1])     # [1] =direction 0/1=down/up
    time.sleep_ms(POWER_SWITCH_DELAY_MS)
    pm.value(sw2[0])     # motor on/off

def setWater(num, onOff=None):
    """set the pins to control the water valves. onOff = 0|1"""
    if globs.verbosity:
        print("w:",num,onOff)
    if not isinstance(num,int):
        num = int(str(num).replace("'","")[-1])
    if not isinstance(onOff,int):
        onOff = int(str(onOff).replace("'","")[-1])
    p=[PIN_WATER1, PIN_WATER2, PIN_WATER3, PIN_WATER4][num-1]
    p.value(onOff)

def setDose(num, onOff=None):
    """set the pins to control general purpose output. onOff = 0|1"""
    if globs.verbosity:
        print("d:",num,onOff)
    if not isinstance(num,int):
        num = int(str(num).replace("'","")[-1])
    if not isinstance(onOff,int):
        onOff = int(str(onOff).replace("'","")[-1])
    p=DOSEN[num-1]
    p.value(onOff)

def getMotor(num, lang=""):
    """
     num: 1|2
     lang: if 'de' then return german texts
     retval: 0/aus, d/zu, u/auf
    """
    num=int(num)
    pd=[PIN_MOTOR1D, PIN_MOTOR2D][num-1]
    pm=[PIN_MOTOR1, PIN_MOTOR2][num-1]
    m = pm.value()
    d = pd.value()
    if lang == "de":
        status = ["Aus", "Zu", "?", "Auf"][m | (d << 1)]
    else:
        status = ["0","d","?","u"][m|(d<<1)]
    return status

def getWater(num, lang=""):
    """
     num: 1|2
     lang: if 'de' then return german texts
     retval: 0/Zu, d/zu, u/Auf
    """
    p=[PIN_WATER1, PIN_WATER2, PIN_WATER3, PIN_WATER4][num-1]
    v=p.value()
    if lang == "de":
        return ["Zu", "Auf"][v]
    return v

def getDose(num, lang=""):
    p=DOSEN[num-1]
    v=p.value()
    if lang == "de":
        return ["Aus", "An"][v]
    return v

def toggleLed():
    """toggle the on-board-led"""
    PIN_LED1.value(not PIN_LED1.value())

def getTime(offset_m=None):
    """
    param: offset in minutes
    returns: time as string in format HH:MM:SS
    """
    d = RTC().datetime()
    if offset_m:
        d = list(d) 
        if offset_m > 23*60:
            offset_m = 23 * 60
            print("Warnung! offset sehr gross:"+str(offset_m))
        d[5]+=offset_m
        while d[5]>59:
            d[5]-=60
            d[4] += 1   # next hour
        if d[4] >23:
            d[4] -= 24  # next day
    return f"{d[4]:02}:{d[5]:02}:{d[6]:02}"

def dictLower(d):
    """change keys in dict to lower case ==> keys are not case sensitive"""
    for k in list(d):
        if isinstance(d[k], dict):
            dictLower(d[k])
        if k.lower() != k:
            d[k.lower()] = d.pop(k)

def pubconfig(cfg):
    """return only config values, which are not private"""
    cfg_tmp = dict(cfg)
    for c in SECRET_GLOBS:
        cfg_tmp.pop(c ,None)  # remove secrets before show cfg
    return cfg_tmp

def readConfig(filename="gwxctrl.cfg"):
    """read config file and update globs.cfg with the result"""
    cfg = None
    msg = "Lese Einstellungen von:"+filename
    if globs.verbosity:
        print(msg)
        comu.addTx(msg)
    try:
        with open(filename,"r") as f:
            cfg = json.load(f)
        if not cfg:
            msg = "Fehler! konnte config nicht laden!"
            print(msg)
            comu.addTx(msg)
            return
        dictLower(cfg)
        globs.cfg.update(cfg)
        msg = "Einstellungen geladen"
        if "verbosity" in cfg:
            globs.verbosity = cfg["verbosity"]
        if globs.verbosity is None:
            globs.verbosity = 0
        if isinstance(globs.verbosity, str):
            try:
                globs.verbosity = int(globs.verbosity)
            except:
                globs.verbosity = 0
        if globs.verbosity:
            msg += str(pubconfig(cfg))
            print(msg)
            comu.addTx(msg)
    except Exception as e:
        msg = "!!! Fehler in readConfig !!!"+str(e)
        print(msg)
        comu.addTx(msg)
    return


def updateConfigFile(addcfg, filename="gwxctrl.cfg"):
    """update config file with new settings"""
    cfg = None
    with open(filename, "r") as f:
        cfg = json.load(f)
    if not cfg:
        msg = "Fehler! konnte config nicht laden!"
        print(msg)
        comu.addTx(msg)
        return False
    dictLower(cfg)
    dictLower(addcfg)
    for k in DO_NOT_UPDATE:
        addcfg.pop(k,0)
    if not addcfg:
        comu.addTx("empty cfg!")
        return False
    cfg.update(addcfg)
    with open(filename, "w") as f:
        json.dump(cfg, f)
    return True

def deleteFromConfigFile(key, filename="gwxctrl.cfg"):
    """delete one entry from configfile"""
    cfg = None
    with open(filename,"r") as f:
        cfg = json.load(f)
    if not cfg:
        msg = "Fehler! konnte config nicht laden!"
        print(msg)
        comu.addTx(msg)
        return 1
    dictLower(cfg)
    cfg.pop(key.lower())
    with open(filename,"w") as f:
        json.dump(cfg,f)
    return 0

def init():
    print("GwxControl version:" + str(__version__))
    # globs.checkWindowPosition_lastTime = time.time()
    readConfig(globs.cfgfile)
    diameter=globs.cfg.get("windsensordia",None)
    if diameter is not None:
        diameter=float(diameter) 
    globs.ws = windsensor.Windsensor(PIN_WIND, 
                    diameter=diameter)
    globs.ws.verbosity = globs.verbosity

    addr1 = globs.cfg.get("sensoraddr1")      # this is None, if not given
    f=globs.cfg.get("sensf1")
    globs.hy1 = HYT221.HYT221(PIN_SCL1, PIN_SDA1, addr1, freq=f)    # if addr1 is None, default is used
    addr2 = globs.cfg.get("sensoraddr2")
    f=globs.cfg.get("sensf2")
    globs.hy2 = HYT221.HYT221(PIN_SCL2, PIN_SDA2, addr2, freq=f)
    globs.hy1.verbosity = globs.verbosity
    globs.hy2.verbosity = globs.verbosity

    comu.globs.callbackRx = servCB
    comu.globs.verbosity = globs.verbosity
    ADC_BATT.atten(machine.ADC.ATTN_11DB)    # set to 3.3V range
    ADC_POWER.atten(machine.ADC.ATTN_11DB)
    esp32.wake_on_ext0(pin=PINNUM_POWER, level=esp32.WAKEUP_ANY_HIGH)

    ak = globs.cfg.get("ak")  # this key used for updates over the air, or critical config-values
    if ak:
        docrypt.init(ak = ak)

    comu.init(2, globs.cfg.get("baudrate"))
    rc = machine.reset_cause()
    comu.addTx("resetcause:"+str(rc))
    if globs.verbosity:
        print("resetcause:"+str(rc))
    if machine.DEEPSLEEP_RESET == rc:
        if globs.verbosity:
            print("wake up from deepsleep...")
        # read values from nvr
        cfg = RTC().memory()
        RTC().memory(b"")  # erase, don't use this values next time
        comu.addTx(cfg)
        time.sleep(1)  # time for client to send infos, before goto deep sleep again
        try:
            cfg = json.loads(cfg)
            globs.lasttime = cfg.get("t")
            if cfg.get("deepsleeprepeat"):
                globs.deepsleep_ms = int(cfg.get("ds") * 1000)
        except Exception as e:
            # cfgok=0
            comu.addTx("Fehler: Lesen von RTC-RAM:"+str(e))
        # if voltage is back, clear deepsleep
        if getVCCVolt() >4:
            globs.deepsleep_ms = 0
    for i in range(1,5):
        try:
          with open(f"watertimetable{i}.dat","rb") as f:
            globs.watertables[i-1] = f.read()
        except Exception as e:
            print(f"error wt{i}: "+str(e))

    globs.lasttime = getTime()
    
    pinsReset()
    
    if globs.cfg.get("test_activated"):
        globs.hy1.testremotecontrol=(0,41,21)
        globs.hy2.testremotecontrol=(0,42,22)
        PIN_END1UP.on()  # for simulator only
        PIN_END1DOWN.on()
        PIN_END2UP.on()
        PIN_END2DOWN.on()

    if globs.verbosity:
        print("init done.")
    globs.inited = True

def pinsReset():
    PIN_WATER1.value(0)
    PIN_WATER2.value(0)
    PIN_WATER3.value(0)
    PIN_WATER4.value(0)
    for d in DOSEN:
        d.value(0)
    PIN_MOTOR1.value(0)
    PIN_MOTOR1D.value(0)
    PIN_MOTOR2.value(0)
    PIN_MOTOR2D.value(0)

def getTH(sensor,num):
    """Sensor for temperature and humidity"""
    try:
        s=sensor.getValues(postdec=1)
        t,h = s.temperature, s.humidity
    except Exception as e:
        t,h = "-", "-"
        if globs.verbosity:
            print("err.Th:"+str(e))
    return f"T{num}:{t};H{num}:{h}"

def parseMsg():
    """execute cmds in globs.rx"""  # all or one
    try:
        msg=None
        if globs.verbosity > 1:
            print("PM.")
        while globs.rx and not msg:
            msg = globs.rx.pop().strip()
            if globs.verbosity>1:
                print("pM:"+str(msg))
        if not msg:
            return
        if isinstance(msg, bytes):
            msg = msg.decode()
        cmd, val = msg, ""
        if "=" in cmd:
            cmd, val = cmd.split("=", 1)
            val = val.strip() ; cmd = cmd.strip()
        if globs.verbosity > 1:
            print("pM:", cmd, val)
        if cmd[:-1] in ("motor","fenster"):
            num = int(cmd[-1:])-1
            direction = val
            if direction == "?":
                msg = "M1:"+getMotor(1)+". M2:"+getMotor(2)
                if globs.verbosity:
                    print(msg)
                comu.addTx(msg)
            else:
                if val in ('u','d','h',"s"):
                    val = globs.windowpos_map[num].get(val,None)
                else:
                    val = int(val)
                globs.window_pos_dest[num] = val
            return
        if "wasser" in cmd:
            num = cmd[-1:]
            direction = val
            if direction == "?":
                comu.addTx(f"W1:{getWater(1)}, W2:{getWater(2)}, W3:{getWater(3)}, W4:{getWater(4)}")
            else:
                setWater(num, direction)
            return
        if "dose" in cmd:
            num = cmd[-1:]
            direction = val
            if direction == "?":
                comu.addTx(f"D1:{getDose(1)}, D2:{getDose(2)}, D3:{getDose(3)}, D4:{getDose(4)}")
            else:
                setDose(num, direction)
            return
        if "testalarm" in cmd:
            sendAlarm("test:"+str(msg))
            return
        if "fwupdate!!" in cmd:
            sendAlarm("pause für fw-update:"+str(msg))
            # globs.dorun = False
            for i in range(40):
                toggleLed()
                time.sleep(.5)
            print("back.")
        if "fwmainstop!!" in cmd:
            sendAlarm("stop für fw-update:"+str(msg))
            globs.dorun = False
        if "todos?" in msg:
            comu.addTx(str(globs.todos))
        elif "todo" in msg:
            if "grfx" in val:
                val = val.replace("grfx","")
                if globs.verbosity: print("todo:"+str(val))
                globs.todo.append(val)
        if "globs?" in msg:
            g = dict(globs.__dict__)    # make a copy
            g.pop("cfg", None)
            comu.addTx(str(pubconfig(g)))
        if "cfg?" in msg:
            comu.addTx(str(pubconfig(globs.cfg)))
        if "verbosity" in cmd:
            globs.verbosity = int(val)
            comu.globs.verbosity = int(val)
        if "interval" in cmd:
            globs.loop_sleep = int(val)/10
            comu.addTx(f"loop sleep:{globs.loop_sleep}s")
        if "rtc" == cmd:
            ti = val.split(',')
            tii=[]
            for t in ti:
                tii.append(int(t))
            while len(tii)<8:
                tii.append(0)
            RTC().init(tii)
        if "reset!" == cmd:
            machine.reset()
        if "deepsleep" in cmd:
            globs.deepsleep_ms = int(val)*1000
            if globs.verbosity:
                print(f"deepsleep {globs.deepsleep_ms} sec.")
            return
        if "bat?" in cmd:
            m = f"Battery: {ADC_BATT.read_uv()*2/1e6} V."
            comu.addTx(m)
            if globs.verbosity:
                print(m)
        if "power?" in cmd:
            m = f"Power: {ADC_POWER.read_uv()*2/1e6} V."
            comu.addTx(m)
            if globs.verbosity:
                print(m)
        if "iv?" in cmd:
            m = f"iv: {hexlify(globs.iv)}."
            comu.addTx(m)
            if globs.verbosity:
                print(m)
        if "i2cscan" in cmd:
            hy = [globs.hy1, globs.hy2][int(val)]
            devs = hy.scan()
            m= "I2C devices found: "+hexlify(bytes(devs),' ').decode()+ \
                "="+str(devs)
            if globs.verbosity: print(m)
            comu.addTx(m)
        if "manually" in cmd:
            globs.manually_timeend = time.time() + int(val)
        if "am:" in cmd[:3]:
                encrypted = cmd[3:]
                m = docrypt.parse(encrypted)
                if globs.verbosity:
                    print(m)
                comu.addTx(m)
        if "modcfgs" in cmd:
            if not val: val=""
            globs.modcfg = val
        if "modcfga" in cmd:
            globs.modcfg += val
        if "modcfg." in cmd:
            globs.modcfg += val
            globs.modcfg = globs.modcfg.replace("'", '"')
            try:
                if globs.verbosity: print(globs.modcfg)
                j=json.loads(globs.modcfg)
                if globs.verbosity: print(str(j))
                if updateConfigFile(j):
                    comu.addTx("updated: "+str(j))
                else:
                    comu.addTx("not updated")
            except Exception as e:
                if globs.verbosity:
                    print("error in parseMsg:" + str(e))
            globs.modcfg = ""
        if "delcfg" in cmd:
            if globs.verbosity: print("del:",val)
            if deleteFromConfigFile(val):
                comu.addTx("delete error")
            else:
                comu.addTx("deleted: "+str(val))
        if "ws" in cmd:
            if globs.ws.testremotecontrol is not None:
                globs.ws.testremotecontrol = float(val)
        if "version" in cmd:
            comu.addTx("Version: "+str(__version__))
                
    except Exception as e:
        if globs.verbosity:
            print("error in parseMsg:"+str(e))

def sendAlarm(msg):
    if globs.verbosity:
        print("Alarm:",msg)
    comu.addTx("Alarm:"+str(msg))
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

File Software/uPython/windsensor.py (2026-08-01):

# uPython windsensor
"""
Runs with esp-32 and uPython.
calculate wind speed from pulse-sensor
Written by rundekugel @github 2024
"""

from machine import Pin
import utime
# from machine import Timer

__version__ = "0.1.3"
PI = 3.141592653589793
WINDSENSOR_DIAMETER = 110e-3    # diameter in m


class Filter:
    lastval = None
    size = 2

    def __init__(self, size, initvalue=None):
        if initvalue is not None:
            self.lastval = initvalue
        size = int(size)
        if size <1:
            print("Warning: size must be integer and >0, but is:"+str(size))
            size=1
        self.size = size

    def feed(self, value):
        if self.lastval is None:
            self.lastval = value
            return value
        self.lastval = (self.lastval *self.size + value)/(self.size+1)
        return self.lastval

    def getValue(self, rounded=1):
        return round(self.lastval, rounded)

class FilterWindowed:
    lastvals = []
    size = 7
    lastav = 0

    def __init__(self, size, initvalue=None):
        if initvalue is not None:
            self.lastval = initvalue
        size = int(size)
        if size <1:
            print("Warning: size must be integer and >0, but is:"+str(size))
            size=1
        self.size = size

    def feed(self, value):
        self.lastvals.append(value)
        if self.size <2:
            return value
        while len(self.lastvals) > self.size:
            self.lastvals.pop(0)
        b = list(self.lastvals)
        b.sort()
        if len(b)>2: b.pop() # remove biggest value
        av = 0
        for i in b:
            av += i
        av /= len(b)
        self.lastav = av
        return av
        
    def getValue(self, rounded=1):
        return round(self.lastav, rounded)

class Windsensor:
    pin = None
    lasttime = None
    lastdelta = None
    speed = None
    diameter = WINDSENSOR_DIAMETER # diameter in m
    proportionalityfactor = 2.6
    circumference = None
    filter = None
    verbosity = 1
    testremotecontrol = None
    

    def __init__(self, pin, diameter=None, filtersize=None):
        """param: pinnumber for data input"""
        self.pin = Pin(pin, Pin.IN, pull=Pin.PULL_UP)
        self.lasttime = utime.ticks_ms()/1e3
        # self.pin.irq(trigger=Pin.IRQ_RISING, handler = self.pinhandler)
        # self.pin.irq(trigger=Pin.IRQ_FALLING, handler = self.pinhandler)
        self.pin.irq(trigger=Pin.IRQ_RISING|Pin.IRQ_FALLING, handler = self.pinhandler)
        if diameter:
            self.diameter = diameter
        self.circumference = self.diameter * PI
        if filtersize is None: filtersize = 7
        self.filter = FilterWindowed(filtersize)

    def __del__(self):
        print("del"+str(self))
        self.pin.irq(handler=None)
        print("fin.")

    def pinhandler(self, pin):
        min_delta = 1e-3    # avoid divide by zero
        d = utime.ticks_ms()/1e3 - self.lasttime
        # debouncing
        if d < min_delta:
            if self.verbosity>1:
                print("invalid d:", d)
            self.lasttime = utime.ticks_ms()/1e3
            return
        self.lastdelta = d
        self.lasttime = utime.ticks_ms()/1e3
        # speed is calculated from delta time, circumference and a proportionalityfactor
        # because we get irq twice (for hi and lo) we devide the value by 2
        speed = (self.circumference /
                (self.lastdelta * self.proportionalityfactor)) /2
        self.speed = self.filter.feed(speed)
        if self.verbosity>1:
            print("d:",self.lastdelta)
            print("m/s:",self.speed)

    def getValue(self, rounded=1):
        """wind m/s"""
        # print(utime.time(), self.lasttime, self.lastdelta)
        # after 1 second asume no wind
        if self.testremotecontrol is not None:
            print("Warnung: windsensor liefert nur testwerte!")
            return self.testremotecontrol
        if utime.ticks_ms()/1e3 > self.lasttime + 1:
            self.speed = 0
        if self.verbosity >1:
            print("d:",self.lastdelta)
            print("m/s:",self.speed)
        return round(self.speed, rounded)


if __name__ == "__main__":
    print("Windsensor Version:"+__version__)
    ws = Windsensor(4)
    for i in range(100):
        val = ws.getValue()
        print("m/s:",val)
        utime.sleep(1)

# eof

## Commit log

2024-04-23 first draft
    [gwx-3p-control-oc.brd, gwx-3p-control-oc.sch, gwx-control.brd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]
2024-04-23 added power switch protection
    motor will stop for a few seconds, if direction changes
    [gwx-control.brd, gwx-control.sch]
2024-04-23 added direction changer brd
    [relais.brd]
2024-05-01 Trigger fixed
    [gwx-control.brd, gwx-control.sch]
2024-05-01 force motor off is now more relyable
    changed from pull down the base of t1 to active switch a 2n T in series
    [gwx-control.brd, gwx-control.sch]
2024-05-01 Changed Motor force off to non inverted mono flop output
    [gwx-control.brd, gwx-control.sch]
2024-05-01 added alternative SMD diode
    [gwx-control.brd, gwx-control.sch]
2024-05-01 pcb size cahnged to 33x54
    [gwx-control.brd]
2024-05-01 LEDs added
    [gwx-control.brd, gwx-control.sch]
2024-05-12 Motor out sign fixed (+)==>(-)
    [gwx-control.brd]
2024-05-13 reading of humidity sensor HYT-221 in µPython
2024-05-13 i2c works now also for ESP32
2024-05-24 HYT221 changed to class, to support multiple sensors
2024-05-25 initial windsensor class for pulse wind sensors
2024-05-25 prepared for 2 sensors
2024-05-25 exchanged wifi with uart for core controller
    uart is more stable.
2024-05-25 set/get motor state prepared
2024-05-25 RTC added
    [gwxctrl.cfg]
2024-05-25 cfg is parsed. cfg not case-sensitive, now
    all cfg is overwritten lower case
    getTime() with optional offset for timer
    [gwxctrl.cfg]
2024-05-26 testmode remote control for HYT221 implemented
    [gwxctrl.cfg]
2024-05-26 set water timer only, if needed
    [gwxctrl.cfg]
2024-05-26 windsensor pin changed. motor id typo fix.
    [gwxctrl.py]
2024-05-27 support deepsleep for ESP32
2024-05-27 Battery Voltage and power supply readable
    [gwxctrl.cfg]
2024-05-27 ADC calc adjusted to hardware voltage divider
2024-05-27 ligtsleep on power loss, deep sleep on low batt voltage
2024-05-28 mock up
    [gwxctrl.cfg]
2024-06-09 new pins
    [gwxctrl.cfg]
2024-06-10 pinning for esp32-light
2024-06-10 degree symbol broke uart data sending
    [comu.py, gwxctrl.py]
2024-06-30 remove secrets before tx
    [gwxctrl.cfg]
2024-07-01 fix for json compatibility
    [gwxctrl.py]
2024-07-01 sensor data in html table
2024-07-02 wind speed without thousands of post decimal positions
    and controller temp display although TH-sensor not available
2024-07-04 decryptor moved. i2cscan added.
2024-07-07 i2c freq. lower
    try to solve "sensor not found"
2024-07-31 Fix show humidity value for sensor1
2024-07-31 added config of sensor frequency
2024-08-09 New: voltage supply monitor for 3 phases
2024-08-15 added a voltage calc divider
2024-08-17 added mqttbuf-service config file
    [mqttbuf.cfg]
2024-09-03 disabled unallowed pin
2024-09-06 don't show secret config values
    [gwxctrl.cfg]
2024-09-18 wdt init int fix
    [gwxctrl.py]
2024-09-18 motor buttons added
2024-09-19 translator for old fw short key (m1) ==> long (motor1)
2024-09-20 hide buttons, if not authorized
2024-09-20 buttons format
2024-09-21 end switch feature
    calculate a virtual model of window angle by time of motor state on
    windsensor prop fac. added
2024-09-21 new keywords for states of motor, windows, temp. and humidity
    for motors' and windows' state
2024-09-22 added login and buttons to tec1
2024-09-22 switcher can use globs and cfg
2024-09-22 windsensor filter changed to windowed sorted filter
2024-09-23 watertables index fix
    + avoid publish SECRET_GLOBS
    [gwxctrl.py]
2024-09-23 added keyword RTC to switcher
2024-09-23 updated manuell buttons
2024-09-23 on too high humidity, close window only, if temperature is < max
    [gwxctrl.py]
2024-09-23 deal with wrong value in "globs.verbosity"
    [gwxctrl.py]
2024-09-24 fixed some typos; mockup
    [gwxctrl.py]
2024-09-25 empty val error fix.val init str/bytes fix
    [gwxctrl.py]
2024-09-26 parse key USB fix for voltage display
2024-10-29 updateconfig fix for float values
    [gwxctrl.py]
2024-12-26 tiny, but powerful design enhancement
2024-12-26 switch manually js fix
2025-03-21 prevent watchdog from to short intervals
    wdttime default= 90
    minimum= 30
    [gwxctrl.py]
2025-03-21 avoid crash, if haus-vars missing
    [gwxctrl.py]
2025-03-28 wifi sockets added
    [gwxctrl.cfg]
2025-03-30 motor halb feature prepared
2025-04-05 delete buffer after "modcfg.", even if error
    loop_sleep reduced, we are slow enough.
    [gwxctrl.py]
2025-04-05 fixed: window goes up if position negative
    [gwxctrl.py]
2025-04-06 motordelay implemented
    if one window at endposition let the other motor run one more second
2025-04-06 motor/fenster cmd can be 0-100 and u,d,h,s
    fenster destination can be:
    (u)p, (d)own, (s)stop, (h)alf.
    or any integer. alowed is only 0-100 !
2025-05-02 added schematic as pdf
2025-05-02 gwx-control-simple pcb and sch as pdf added
2025-05-10 moved services to new folder server-services
    [mqttbuf.cfg]
2025-05-31 human readable device names
2025-06-20 motor cmd '0' ==> 's'
2025-06-22 waits added, for direction switch relais.
2025-06-22 uart uses flush, before write
2025-06-24 alarm for min. temp added
    comu: ignore, if uart.flush not available
2025-08-04 fixed typo time_ms => sleep_ms
    [gwxctrl.py]
2026-02-15 updateconfig.cfg as default
    [config-w-h1.cfg]
2026-06-04 Config transfer button prepared
2026-06-09 kicad files added
    [gwx-3p-control-oc.kicad_pcb, gwx-3p-control-oc.kicad_sch]
2026-06-09 kicad project file
2026-08-01 Fixed motor stops during moving.
    [docrypt.py, gwxctrl.py, windsensor.py]
2026-08-01 New configvalue allows to set max position of window at strong wind.
    [gwxctrl.cfg]
2026-08-07 V3.0
    mainboard with bluepill
    [gwx-control.kicad_pcb, gwx-control.kicad_sch, gwx-control.sch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]
2026-08-07 Changed to 2x8 connector
2026-08-07 LEDs libs updated
2026-08-09 universal gwxctrl for esp32 and blackpill
2026-08-09 merged branch blackpill to main
    default hwspec.py: esp32lite
2026-08-09 V0.6.0 water can set manually
    Added valid pins to hw-esp32lite
    Sanitary check for valie hw-spec values
    Use only as much watertables as water-valve-pins defined
    Same for GPIO-Switches "Dosen"
2026-08-09 fixed esp32lite pins
    Now changed to old settings from 2025-06-20
    Was configured for esp32-s3
2026-08-09 Window closes to max value on strong wind. Override changed.
    For strong wind: max. open window position can be configured.
    Sensor values can be overwritten by testvalues.
2026-08-09 Pins fix for esp32lite
2026-08-09 PCB shrinked
2026-10-27 Prepared reading of motor direction sensors.
